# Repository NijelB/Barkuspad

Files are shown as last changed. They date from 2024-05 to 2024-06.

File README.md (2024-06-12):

# Barkuspad
Welcome, here you will find parts and resources for all versions of the Barkus pad. This also includes dance pad firmware for the NanoESP Development board, I hope someday this board, or another ESP32S3-based development board will become the go-to for all DIY game controllers.

# Benifits of ESP32:
### 20 Analog Channels
allowing all kinds of different sensor configs up to 20 sensors.
### USB-C
### 240MHZ Dual core processor
Making it 30x as fast as a 16MHZ USB-C Arduino Micro clone if you use both cores. 1000HZ polling can easily be maintained with this processor even with other heavy loads like a display and Bluetooth. 
### Native HID support
No need for workarounds like UnoJoy that require tampering with the bootloader.
### Native Bluetooth HID support
This could be really cool for travel pads. Imagine embedding this controller within a travel pad and powering it via a UL, CE, Etc... certified USB power bank, we could have cheap and easily made TSA-friendly Bluetooth travel pads.
### Extremely flexible GPIO Pin mapping
### Low cost
A WaveShare dev board can be had for 8$ USD, furthermore, the chip itself costs only 3$ USD.
<br><br>
The ESP32S3 is super promising, I hope to provide a good demonstration of its power to the dance pad community.
<br><br>

# Plastic Parts:
There are folders for most of the 3d printed parts of the pad in here with details such that replacement parts can be made independently. Just open the folder for the version of the pad you have and open the parts folder, then follow the instructions for said part.

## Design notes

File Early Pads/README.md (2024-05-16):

These are all of the early pads that were designed and made, no more than 30 were ever made so they've been put in a seperate folder from the main folder. Due to the low amount of these pads that actually exist and large amount of files there aren't per file printing instructions, but as a baseline:
<br> 40% infill, 2 wall lines, 4 top layers, 4 bottom layers will work for all of the plastic parts here.
<br> 20% gyriod infill, 1 wall line, 4 top, 4 bottom layers will be a good starting point for the TPU parts.

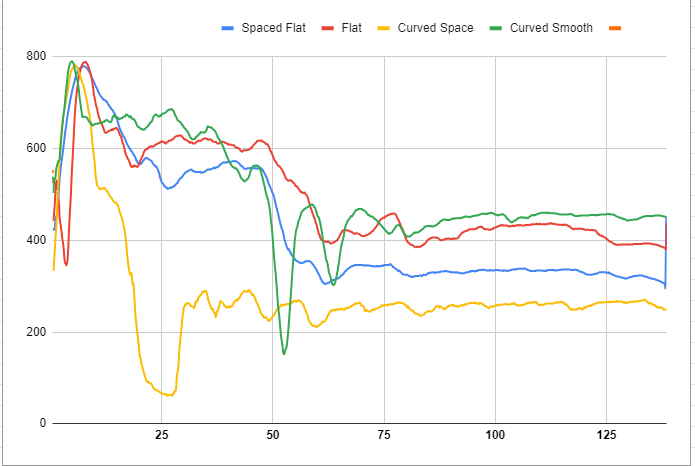
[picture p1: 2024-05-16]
Barkuspad 1_4/sensordata.PNG

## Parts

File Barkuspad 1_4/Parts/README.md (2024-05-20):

Printing instructions:
<p>
Button_base:
<br>-layer height: 0.24mm
<br>-infill: 40%
<br>-wall thickness: 2mm
<br>-top layers: 2
<br>-bottom layers: 4
<p>
Button_Button:
<br>-layer height: 0.24mm
<br>-infill: 40%
<br>-wall thickness: 2mm
<br>-top layers: 2
<br>-bottom layers: 4
<p>
CboxBase:
<br>-layer height: 0.24mm
<br>-infill: 40%
<br>-wall thickness: 1mm
<br>-top layers: 2
<br>-bottom layers: 4
<p>
CboxTop:
<br>-layer height: 0.24mm
<br>-infill: 40%
<br>-wall thickness: 1mm
<br>-top layers: 2
<br>-bottom layers: 6
<p>
Tile_Base:
<br>-layer height: 0.24mm
<br>-infill: 40%
<br>-wall thickness: 1.5mm
<br>-top layers: 2
<br>-bottom layers: 2
<p>
CornerPiece:
<br>-layer height: 0.24mm
<br>-infill: 40%
<br>-wall thickness: 2mm
<br>-top layers: 2
<br>-bottom layers: 4
<p>
GFXClip:
<br>-layer height: 0.24mm
<br>-infill: 40%
<br>-wall thickness: 1mm
<br>-top layers: 4
<br>-bottom layers: 4
<p>
Inner contact base:
<br>-layer height: 0.24mm
<br>-infill: 40%
<br>-wall thickness: 1mm
<br>-top layers: 4
<br>-bottom layers: 4
<p>
Inner contact tpu:
<br>-layer height: 0.24mm
<br>-infill: 60%
<br>-wall thickness: 1mm
<br>-top layers: 2
<br>-bottom layers: 2

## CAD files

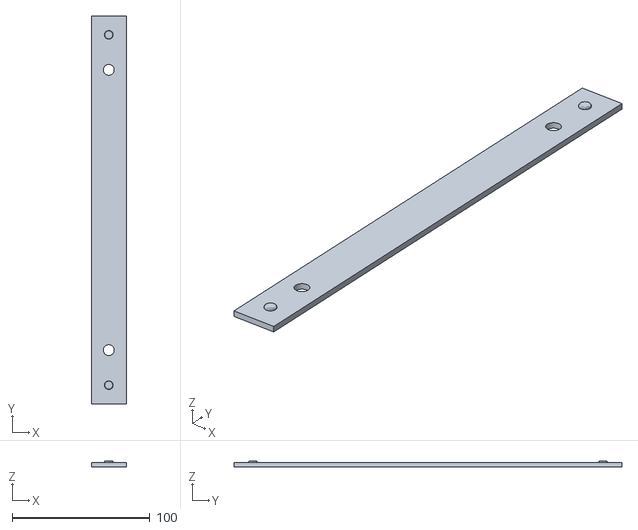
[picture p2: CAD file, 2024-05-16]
Barkuspad 1_4/Parts/Contacts/Outer_contact_spacer.stl
25.1 x 281.3 x 4.44

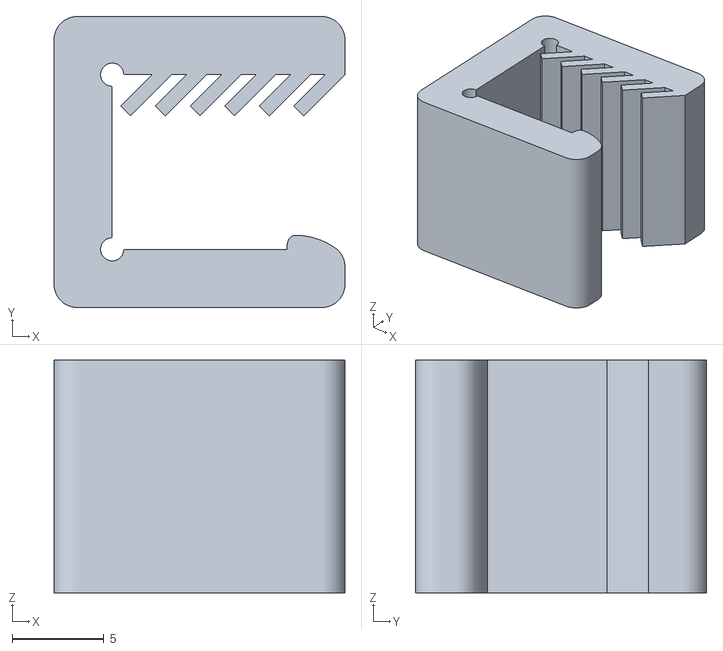
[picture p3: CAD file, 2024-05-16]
Barkuspad 1_4/Parts/GFXClip.stl
15.9 x 15.9 x 12.7

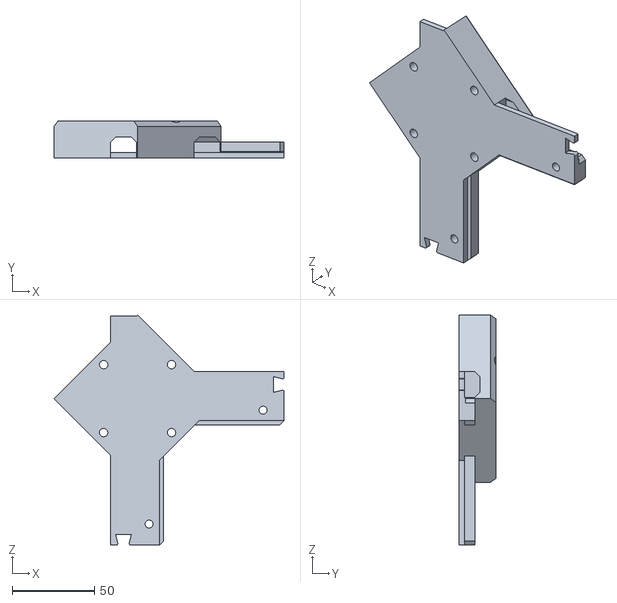
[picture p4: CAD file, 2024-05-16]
Early Pads/Barkuspad 1_1/Parts/BodyPieces/Corner_Brace_1.STL
139.7 x 22.2 x 139.7

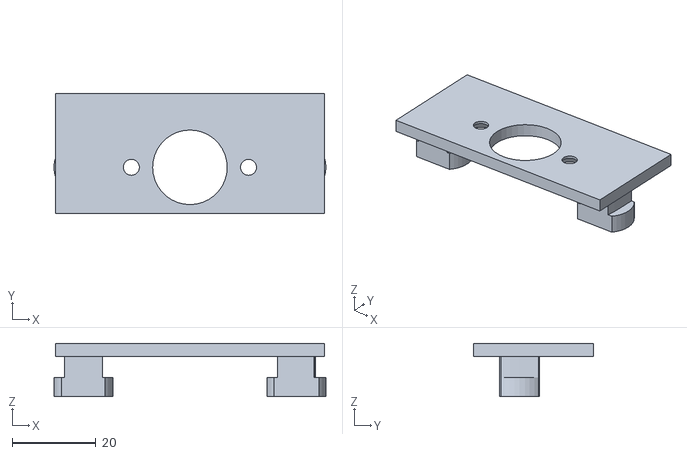
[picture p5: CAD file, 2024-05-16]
Early Pads/Barkuspad 1_1/Parts/Case/MOUNT1_1.STL
64.9 x 28.7 x 12.7

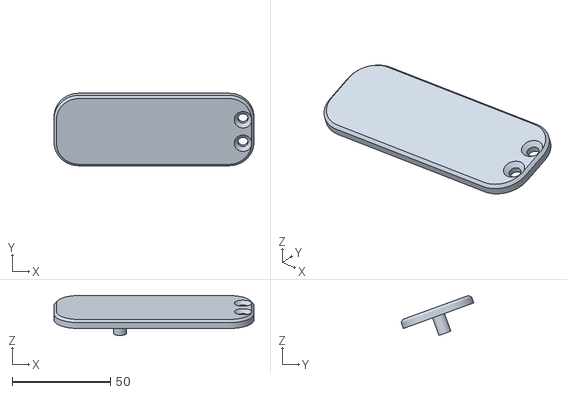
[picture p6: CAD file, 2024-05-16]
Early Pads/Barkuspad 1_1/Parts/Control panel/Start select button.stl
101.6 x 36.9 x 20.3

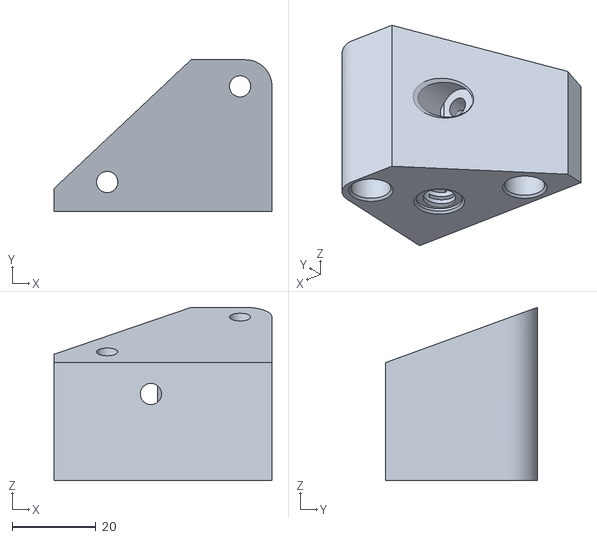
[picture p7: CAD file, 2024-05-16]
Early Pads/Barkuspad 1_1/Parts/PanelPieces/Panel support threaded L.stl
52.1 x 36.2 x 41.4

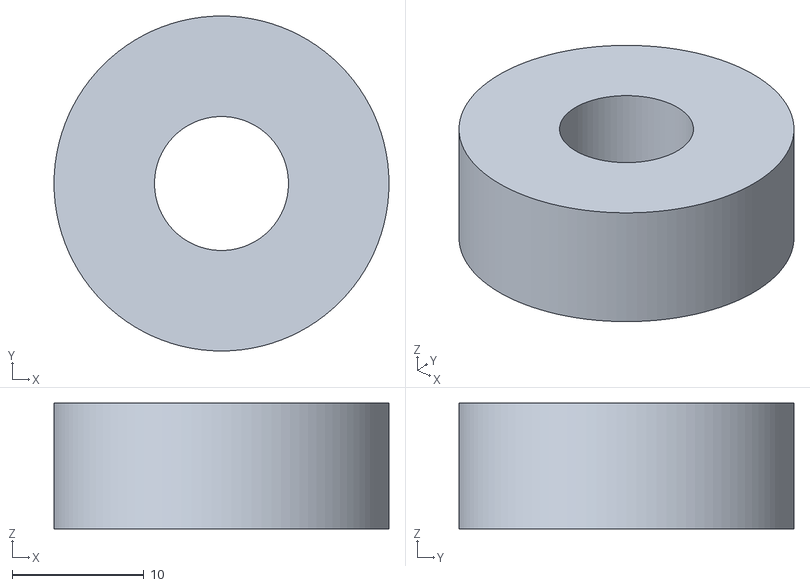
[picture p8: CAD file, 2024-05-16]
Early Pads/Barkuspad 1_1/Parts/Printing Files/New375Support.stl
25.4 x 25.4 x 9.53

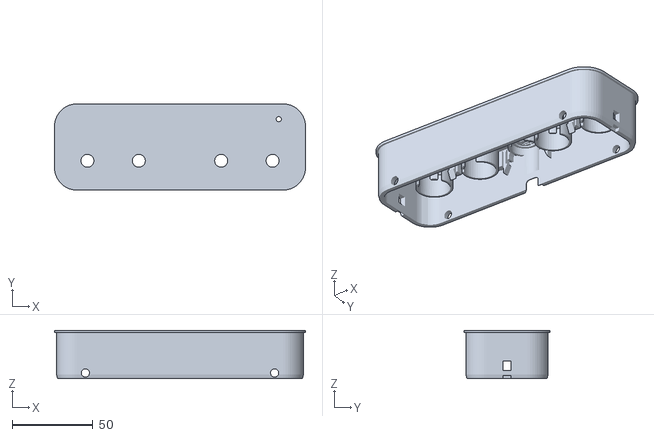
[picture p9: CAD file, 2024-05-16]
Early Pads/Barkuspad 1_2/Parts/Newest_control_box.stl
154.9 x 53.3 x 29.8

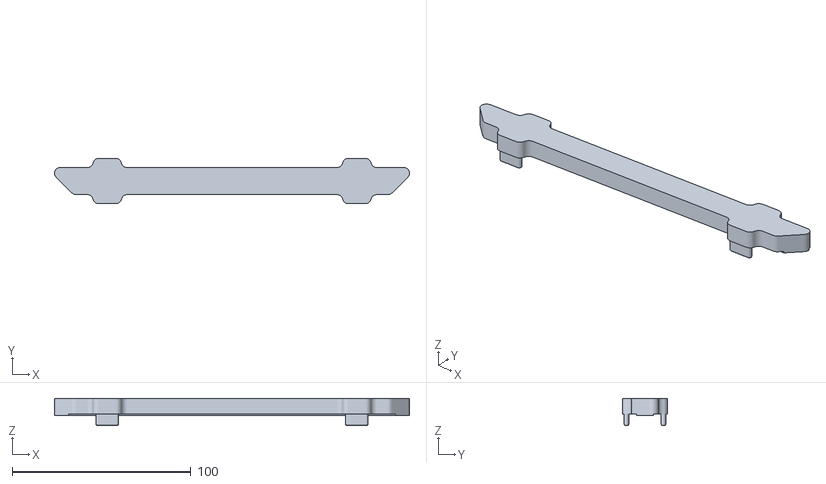
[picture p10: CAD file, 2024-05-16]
Early Pads/Barkuspad 1_3/Parts/Contacts/InnerBumper1.stl
198.8 x 25.4 x 15.3

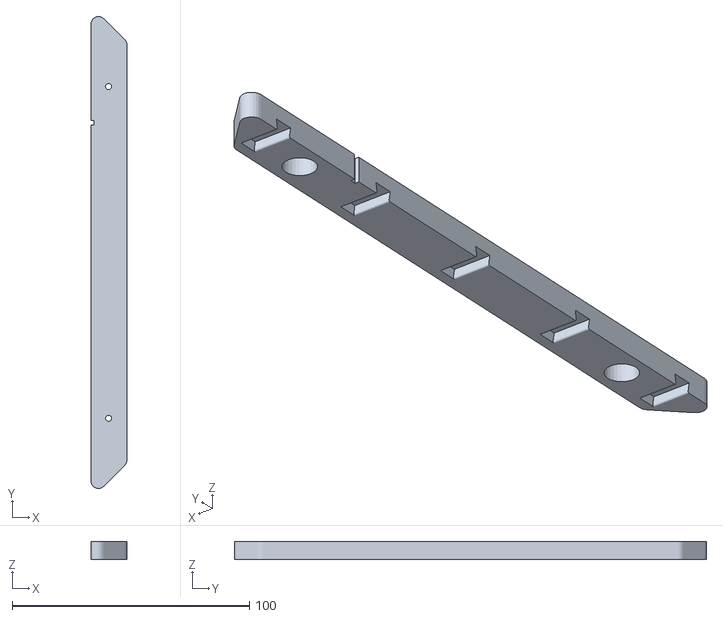
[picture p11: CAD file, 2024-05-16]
Early Pads/Barkuspad 1_3/Parts/Contacts/V2 Bumpers/HardBumberI.stl
15.2 x 198.8 x 7.62

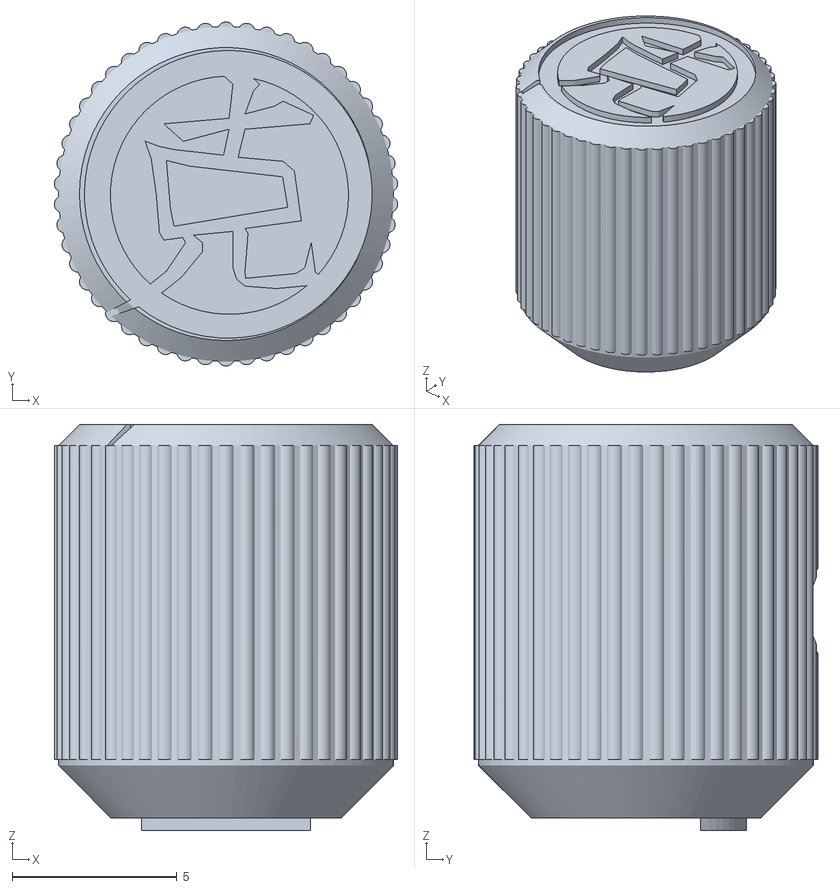
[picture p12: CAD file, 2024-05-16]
Early Pads/Barkuspad 1_3/Parts/knob.stl
10.4 x 10.4 x 12.3

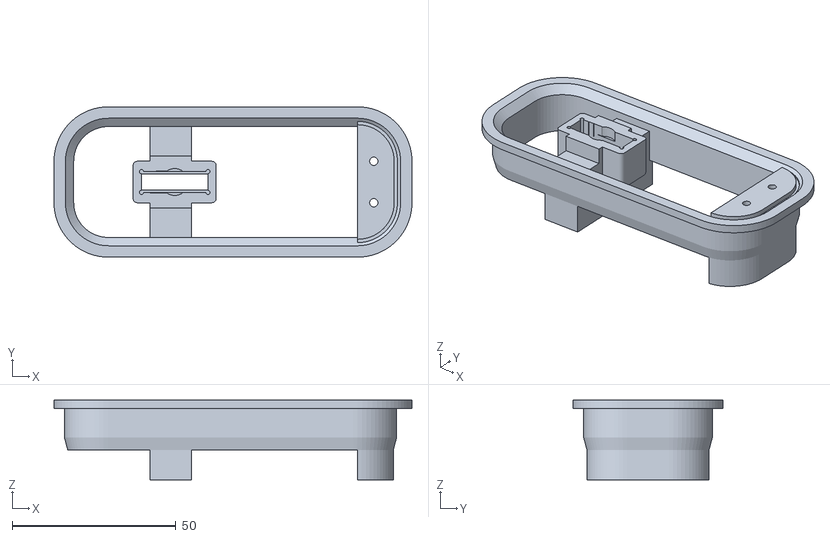
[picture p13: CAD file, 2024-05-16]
Barkuspad 1_4/Parts/Button_base.stl
109.5 x 46.0 x 24.4

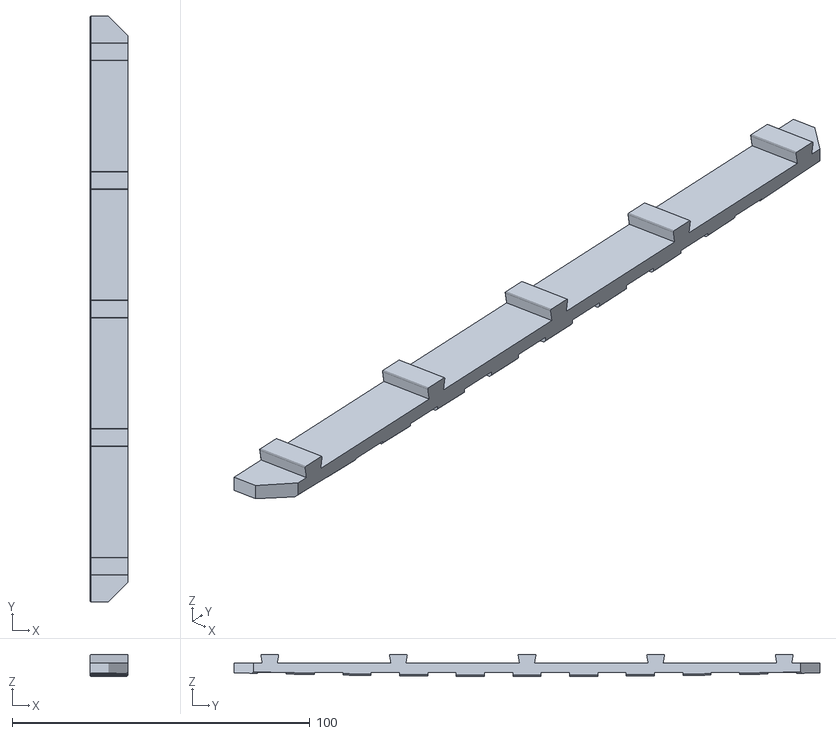
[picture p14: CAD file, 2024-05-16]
Barkuspad 1_4/Parts/Contacts/Inner_contact_tpu_short.stl
12.7 x 196.9 x 7.49

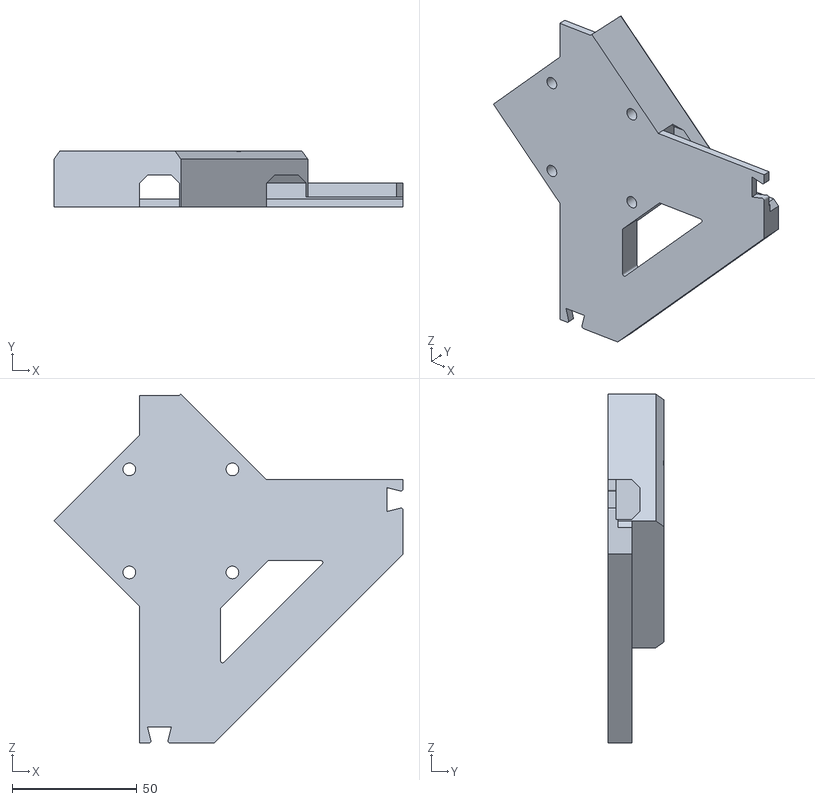
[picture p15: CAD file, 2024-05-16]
Early Pads/Barkuspad 1_1/Parts/BodyPieces/Corner_Brace_3.STL
139.7 x 22.2 x 139.7

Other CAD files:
Early Pads/Barkuspad 1_1/Parts/Case/LID1_1.SLDPRT.STL
Early Pads/Barkuspad 1_1/Parts/Control panel/Start select button base.stl
Early Pads/Barkuspad 1_1/Parts/PanelPieces/Contact.STL
Early Pads/Barkuspad 1_1/Parts/Printing Files/Control Box Cover Ramped.stl
Barkuspad 1_4/Parts/CBoxBot.stl
Barkuspad 1_4/Parts/CBoxTop.stl
Barkuspad 1_4/Parts/Contacts/Inner_contact_base.stl
Barkuspad 1_4/Parts/Contacts/Inner_contact_tpu_tall.stl
Barkuspad 1_4/Parts/CornerPiece.stl
Barkuspad 1_4/Parts/Tile_Base.stl
Barkuspad 1_4/Parts/button_button.stl
Barkuspad 1_4/Parts/knob.stl
Early Pads/Barkuspad 1_1/Parts/BodyPieces/Corner_Brace_2.STL
Early Pads/Barkuspad 1_1/Parts/BodyPieces/Corner_Brace_4.STL
Early Pads/Barkuspad 1_1/Parts/BodyPieces/Corner_Brace_5.STL
Early Pads/Barkuspad 1_1/Parts/BodyPieces/Corner_Brace_6.STL
Early Pads/Barkuspad 1_1/Parts/BodyPieces/Cross_Brace_1.STL
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

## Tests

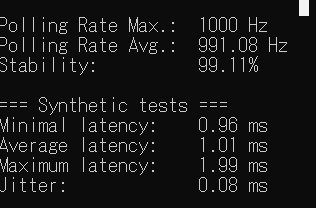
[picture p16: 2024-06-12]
Barkuspad 1_4/Firmware/V8_DUALCORE_MAIN/Testresults.png

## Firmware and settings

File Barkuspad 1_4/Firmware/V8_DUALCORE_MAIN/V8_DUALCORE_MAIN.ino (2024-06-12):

//OBJECTIVES:
//1: Poll at 1000hz 100% stability. 
//2: Have a UI where the user can adjust input sensitivity, see sensor values, and adjust the input pins for backwards compatibility with older pads, or custom pads.
//(3) -- For a later date, setup Bluetooth LE for input. This could be really good for travel pads.


//This sketch uses RTOS, Real Time Operating System. It lets us run the controller on Core1 where it will be uninterupted and is free to run at 1000hz, everything else is on core 0.
//So instead of functions, we have tasks and loops are created from for(;;) instead of loop(). You can still make functions and call them from the tasks but dont add anything to loop(), the reason is loop() runs on core 1 and as previously mentioned, core 1 is reserved for the actual controller input.
//The display can take up to 20ms to render sometimes, during this time previously no other code could run, which is obviously really bad when it comes to having a responsive controller.
//Because loop isnt used we have functions with never ending for(;;) loops. The ESP32 has inbuilt stack overflow protection methods but you still have to be careful what you do with the memory or else it will just crash.
//If you are confused at all the FreeRTOS documentation has really good explanations for everything and there are quite a few basic overviews on youtube.
//TLDR: DO NOT ADD CODE TO THE INPUTCONTROLLER() FUNCTION (or in this case, task), unless it actually has something to do with the controller, that segment needs to be as optimised as possible to maintain good polling rate.

//To program the board you have to press the reset button twice before uploading, it cannot be fast. press 1 second, release one second, press 1 second, release. The light will be a green that fades in and out if you have succeeded.

//THINGS THAT CHANGE BECAUSE WE ARE USING RTOS
//return; is now continue;
//loop() is unused
//we have to manually allocate memory to each task. If you make additions and the board starts crashing you likely need to just increase the #define STACK_SIZE variable to something bigger.

// Serial.println(uxTaskGetStackHighWaterMark(NULL)); <-- USE this command in a function to see how much memory the task uses

#include "USB.h"
#include "USBHIDGamepad.h"
#include <SPI.h>
#include <Wire.h>
#include <Adafruit_GFX.h>
#include <Adafruit_SSD1306.h>
#include <Preferences.h> // ESP32 equivelent of EEPROM

#define SCREEN_WIDTH 128
#define SCREEN_HEIGHT 64
#define OLED_RESET -1
#define SCREEN_ADDRESS 0x3C
#define portTICK_PERIOD_US ( ( TickType_t ) 1000000 / configTICK_RATE_HZ )

#define STACK_SIZE 5000  //They all use ~3200 each so 4000 is a pretty good number

//display stuff
Adafruit_SSD1306 display(SCREEN_WIDTH, SCREEN_HEIGHT, &Wire, OLED_RESET);
int highlightedBar = 3;  // Change this value to highlight a different bar
bool barSelected = false;
int highlightedSetting = 0;
int ButtonHeld = 0;
int refreshInt = 20;

//Settings
String ver = "2024 BARKUS MFG LLC";
enum ScreenSel { //which screen we are on
  MAIN,
  SETTINGS,
  PINREMAP
};
ScreenSel screenSel = MAIN;
bool settingSelected = false;
int scroll = 38;
int pinRemapSel = 0;
int pindex = 0;
bool pinSelected = 0;
int scrollLimit[] = { -52, 38 };
int settings = 9;
int highlightedsetting = 0;
String settingParams[] = { "Back", "Refresh", "Release Thresh", "Press Thresh", "Poll Tester", "Save Settings", "!!Reset All!!", "Inputs", "Pin Remap", "Smoothing" };
int autoSaveInt = 10000;
int autoSaveCounter = 0;
int resetCounter = 0;
int possiblePins[] = {A0, A1, A2, A3, A6, A7, D2, D3};
int smoothingSize = 10; //Window size for sensor smoothing
bool smoothing = true;
unsigned long lastInput;

//Storage
Preferences preferences;

//HID stuff
USBHIDGamepad Gamepad;
bool flipper = false;
bool testPoll = true;

//rotary knob stuff
int CLK_state = 0;
int prev_CLK_state = 0;
int DT_PIN = D7;
int CLK_PIN = D6;
int direction = 0;
int counter;
int buttonPin = D8;
int oldPos = 0;
bool release = true;

////////////////////////////////////////////////////////////////
/**/ int inputPins[] = { A0, A1, A2, A3, A6, A7, D2, D3 };//
////////////////////////////////////////////////////////////////

uint8_t inputs = 4;
int threshVal[] = { 200, 200, 200, 200, 900, 900, 900, 900 };
int sensVal[] = { 40, 70, 30, 50, 10, 70, 10, 10 };
bool bOn[] = { false, false, false, false, false, false, false, false };

//Adjusting these values below may help with jitter inputs (Lightly pressing the tile and getting 10s to 100s of button presses)
int releaseThresh = 10;  //Keep this below press Thresh, default = 10
int pressThresh = 15;    //Keep this above release Thresh, default = 15
void loop() {}           //<== Dont put anything in there
// 'barkusmap', 128x64px
const unsigned char myBitmap[] PROGMEM = {
  0x00, 0x00, 0x00, 0x00, 0x00, 0x00, 0x00, 0x00, 0x00, 0x00, 0x00, 0x00, 0x00, 0x00, 0x00, 0x00,
  0x00, 0x00, 0x00, 0x00, 0x00, 0x00, 0x00, 0x00, 0x60, 0x00, 0x00, 0x00, 0x00, 0x00, 0x00, 0x00,
  0x00, 0x00, 0x00, 0x00, 0x00, 0x00, 0x00, 0x3f, 0xff, 0xe0, 0x00, 0x00, 0x00, 0x00, 0x00, 0x00,
  0x00, 0x00, 0x00, 0x00, 0x00, 0x00, 0x01, 0xff, 0xff, 0xf8, 0x00, 0x00, 0x00, 0x00, 0x00, 0x00,
  0x00, 0x00, 0x00, 0x00, 0x00, 0x00, 0x07, 0xff, 0xff, 0xff, 0x00, 0x00, 0x00, 0x00, 0x00, 0x00,
  0x00, 0x00, 0x00, 0x00, 0x00, 0x00, 0x1f, 0xff, 0xff, 0xff, 0x80, 0x00, 0x00, 0x00, 0x00, 0x00,
  0x00, 0x00, 0x00, 0x00, 0x00, 0x00, 0x7f, 0xff, 0xff, 0xff, 0xe0, 0x00, 0x00, 0x00, 0x00, 0x00,
  0x00, 0x00, 0x00, 0x00, 0x00, 0x00, 0xff, 0xe0, 0x3e, 0x7f, 0xf8, 0x00, 0x00, 0x00, 0x00, 0x00,
  0x00, 0x00, 0x00, 0x00, 0x00, 0x03, 0xff, 0x80, 0x1f, 0x8f, 0xfc, 0x00, 0x00, 0x00, 0x00, 0x00,
  0x00, 0x00, 0x00, 0x00, 0x00, 0x07, 0xfc, 0x00, 0x1f, 0x03, 0xfe, 0x00, 0x00, 0x00, 0x00, 0x00,
  0x00, 0x00, 0x00, 0x00, 0x00, 0x0f, 0xf8, 0x00, 0x1e, 0x00, 0xff, 0x00, 0x00, 0x00, 0x00, 0x00,
  0x00, 0x00, 0x00, 0x00, 0x00, 0x1f, 0xe0, 0x00, 0x1e, 0x00, 0x3f, 0x80, 0x00, 0x00, 0x00, 0x00,
  0x00, 0x00, 0x00, 0x00, 0x00, 0x1f, 0xc0, 0x00, 0x1c, 0x00, 0x1f, 0xc0, 0x00, 0x00, 0x00, 0x00,
  0x00, 0x00, 0x00, 0x00, 0x00, 0x3f, 0x80, 0x00, 0x1c, 0x0f, 0x0f, 0xc0, 0x00, 0x00, 0x00, 0x00,
  0x00, 0x00, 0x00, 0x00, 0x00, 0x7f, 0x00, 0x00, 0x1c, 0xff, 0xe7, 0xe0, 0x00, 0x00, 0x00, 0x00,
  0x00, 0x00, 0x00, 0x00, 0x00, 0xfe, 0x00, 0x00, 0x3f, 0xff, 0xf3, 0xf0, 0x00, 0x00, 0x00, 0x00,
  0x00, 0x00, 0x00, 0x00, 0x00, 0xfc, 0x00, 0x1f, 0xff, 0xff, 0xf1, 0xf8, 0x00, 0x00, 0x00, 0x00,
  0x00, 0x00, 0x00, 0x00, 0x01, 0xf8, 0x07, 0xff, 0xff, 0xc0, 0x01, 0xf8, 0x00, 0x00, 0x00, 0x00,
  0x00, 0x00, 0x00, 0x00, 0x01, 0xf8, 0x03, 0xff, 0x38, 0x00, 0x00, 0xfc, 0x00, 0x00, 0x00, 0x00,
  0x00, 0x00, 0x00, 0x00, 0x03, 0xf0, 0x01, 0xf0, 0x38, 0x00, 0x00, 0x7c, 0x00, 0x00, 0x00, 0x00,
  0x00, 0x00, 0x00, 0x00, 0x03, 0xe0, 0x00, 0x00, 0x38, 0x00, 0x00, 0x7c, 0x00, 0x00, 0x00, 0x00,
  0x00, 0x00, 0x00, 0x00, 0x07, 0xe0, 0x40, 0x00, 0x38, 0x00, 0x00, 0x3e, 0x00, 0x00, 0x00, 0x00,
  0x00, 0x00, 0x00, 0x00, 0x07, 0xe0, 0x78, 0x00, 0x38, 0x00, 0x00, 0x3e, 0x00, 0x00, 0x00, 0x00,
  0x00, 0x00, 0x00, 0x00, 0x07, 0xc0, 0x7f, 0xfc, 0x70, 0x00, 0x00, 0x1f, 0x00, 0x00, 0x00, 0x00,
  0x00, 0x00, 0x00, 0x00, 0x0f, 0xc0, 0x3f, 0xff, 0xfc, 0x00, 0x00, 0x1f, 0x00, 0x00, 0x00, 0x00,
  0x00, 0x00, 0x00, 0x00, 0x0f, 0x80, 0x38, 0x7f, 0xff, 0xfc, 0x00, 0x1f, 0x00, 0x00, 0x00, 0x00,
  0x00, 0x00, 0x00, 0x00, 0x0f, 0x80, 0x38, 0x00, 0xff, 0xfe, 0x00, 0x1f, 0x00, 0x00, 0x00, 0x00,
  0x00, 0x00, 0x00, 0x00, 0x0f, 0x80, 0x38, 0x00, 0x00, 0x7f, 0x00, 0x0f, 0x00, 0x00, 0x00, 0x00,
  0x00, 0x00, 0x00, 0x00, 0x0f, 0x80, 0x38, 0x00, 0x00, 0x03, 0x00, 0x0f, 0x00, 0x00, 0x00, 0x00,
  0x00, 0x00, 0x00, 0x00, 0x0f, 0x80, 0x38, 0x00, 0x00, 0x03, 0x00, 0x0f, 0x80, 0x00, 0x00, 0x00,
  0x00, 0x00, 0x00, 0x00, 0x0f, 0x80, 0x18, 0x00, 0x00, 0x03, 0x80, 0x0f, 0x80, 0x00, 0x00, 0x00,
  0x00, 0x00, 0x00, 0x00, 0x0f, 0x80, 0x18, 0x00, 0x00, 0x03, 0x80, 0x0f, 0x80, 0x00, 0x00, 0x00,
  0x00, 0x00, 0x00, 0x00, 0x1f, 0x80, 0x18, 0x00, 0x00, 0x01, 0x80, 0x0f, 0x80, 0x00, 0x00, 0x00,
  0x00, 0x00, 0x00, 0x00, 0x0f, 0x80, 0x18, 0x00, 0x00, 0x01, 0x80, 0x0f, 0x80, 0x00, 0x00, 0x00,
  0x00, 0x00, 0x00, 0x00, 0x0f, 0x80, 0x18, 0x00, 0x00, 0x01, 0x80, 0x0f, 0x80, 0x00, 0x00, 0x00,
  0x00, 0x00, 0x00, 0x00, 0x0f, 0x80, 0x1c, 0x00, 0x00, 0x0f, 0x80, 0x0f, 0x00, 0x00, 0x00, 0x00,
  0x00, 0x00, 0x00, 0x00, 0x0f, 0x80, 0x1c, 0x00, 0x03, 0xff, 0x80, 0x0f, 0x00, 0x00, 0x00, 0x00,
  0x00, 0x00, 0x00, 0x00, 0x0f, 0x80, 0x1c, 0x00, 0xff, 0xff, 0xc0, 0x0f, 0x00, 0x00, 0x00, 0x00,
  0x00, 0x00, 0x00, 0x00, 0x0f, 0x80, 0x1c, 0x3f, 0xff, 0xe0, 0x00, 0x1f, 0x00, 0x00, 0x00, 0x00,
  0x00, 0x00, 0x00, 0x00, 0x0f, 0xc0, 0x1f, 0xff, 0xfc, 0x00, 0x00, 0x1f, 0x00, 0x00, 0x00, 0x00,
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
};

// 'settingsgear' 8x8px
const unsigned char settmap[] PROGMEM = {
  0x24, 0x00, 0x81, 0x18, 0x18, 0x81, 0x00, 0x24
};

//Sensor value smoothing somewhat similar to the way it works on TeeJUSBs' code. Here we are just calculating WMA instead of WMA and HMA, WMA is already plenty.
class Sensor {
  private:
    int windowSize;
    int* values;
    int currentIndex;

  public:
    Sensor(int windowSize) {
      this->windowSize = windowSize;
      values = new int[windowSize];
      currentIndex = 0;
      for (int i = 0; i < windowSize; i++) {
        values[i] = 0;
      }
    }

    ~Sensor() {
      delete[] values;
    }

    int calculateWMA(int pin_) {
      // Push all values up one index
      for (int i = windowSize - 1; i > 0; i--) {
        values[i] = values[i - 1];
      }
      // Add the new sensor reading at index 0
      values[0] = analogRead(pin_);
      int sum = 0;
      int weight = windowSize;
      for (int i = 0; i < windowSize; i++) {
        sum += values[i] * weight;
        weight--; // Decrease weight for the next value
      }
      return (sum / ((windowSize * (windowSize + 1)) / 2)); // Divide by the sum of the series 1 to windowSize
    }
};

//Would be nice if it could be the same size as the amount of inputs you have selected but the ESP32 is fast enough to cope with the max possible value of 8 and memory fragmentation
//is a very real threat when using RTOS so we will keep it at 8 always
Sensor sensors[8] = {
  Sensor(smoothingSize),
  Sensor(smoothingSize),
  Sensor(smoothingSize),
  Sensor(smoothingSize),
  Sensor(smoothingSize),
  Sensor(smoothingSize),
  Sensor(smoothingSize),
  Sensor(smoothingSize)
};

void setup() {
  //Encoder pin setup
  pinMode(buttonPin, INPUT_PULLUP);
  pinMode(DT_PIN, INPUT_PULLUP);
  pinMode(CLK_PIN, INPUT_PULLUP);

  //Display setup
  if (!display.begin(SSD1306_SWITCHCAPVCC, SCREEN_ADDRESS)) {
    Serial.println(F("SSD1306 allocation failed"));
    for (;;)
      ;  // Don't proceed, loop forever
  }
  display.display();  //Clear Adafruit logo
  delay(2);
  display.clearDisplay();
  display.drawBitmap(0, 0, myBitmap, 128, 64, WHITE);
  display.display();
  delay(5000);  //Change logo displat time here, set to 0 to load immediately <--
  display.clearDisplay();
  
  Gamepad.begin();
  preferences.begin("settings", false); 
  Setting(true, false); // Read settings
  Serial.begin(115200);

  pinMode(inputPins[6], INPUT);
  pinMode(inputPins[7], INPUT);

  xTaskCreatePinnedToCore(
    updateDisplay,
    "DisplayUpdate",
    STACK_SIZE,
    NULL,
    1,
    NULL,
    0);

  xTaskCreatePinnedToCore(
    InputController,
    "controllerinput",
    STACK_SIZE,
    NULL,
    2,
    NULL,
    1);

  xTaskCreatePinnedToCore(
    UIControls,
    "controllerinput",
    STACK_SIZE,
    NULL,
    1,
    NULL,
    0);
}

void Setting(bool ReadOW, bool showMessage){ // First bool decides if you want to read or write to memory, True for read. Second bool decides if you want to display the "settings saved" text
  if (ReadOW == false) { //Write to memory    
    preferences.putBool("testpoll", testPoll);
    preferences.putInt("inputs", inputs);
    for (int i = 0; i < 8; i++) {
      char pointer[50];
      ("thresh" + String(i)).toCharArray(pointer, 50);
      preferences.putInt(pointer, threshVal[i]);
    }
    for (int i = 0; i < 8; i++) {
      char pointer[50];
      ("pinmap" + String(i)).toCharArray(pointer, 50);
      preferences.putInt(pointer, inputPins[i]);
    }
    preferences.putInt("releaseThresh", releaseThresh);
    preferences.putInt("pressThresh", pressThresh);
    preferences.putInt("refreshInt", refreshInt);
  } else { //Read memory
    testPoll = preferences.getBool("testpoll", false);
    inputs = preferences.getInt("inputs", 4);
    for (int i = 0; i < 8; i++) {
      char pointer[50];
      ("thresh" + String(i)).toCharArray(pointer, 50);
      threshVal[i] = preferences.getInt(pointer, 500);
    }
    for (int i = 0; i < 8; i++) {
      char pointer[50];
      ("pinmap" + String(i)).toCharArray(pointer, 50);
      inputPins[i] = preferences.getInt(pointer, possiblePins[i]);
    }
    releaseThresh = preferences.getInt("releaseThresh", 10);
    pressThresh = preferences.getInt("pressThresh", 15);
    refreshInt = preferences.getInt("refreshInt", 20);
  }
  if(showMessage){
    //Show message
  }
}

void SetDefaults(){
  testPoll = false;
    inputs = 4;
    for (int i = 0; i < 8; i++) {
      threshVal[i] = 500;
    }
    for (int i = 0; i < 8; i++) {
      inputPins[i] = possiblePins[i];
    }
    releaseThresh = 10;
    pressThresh = 15;
    refreshInt = 20;
}

void InputController(void* parameters) {
  /* I am faced with an interesting problem here, the ESP32 HID Gamepad library doesnt have a manual send equivelent like Joystick library does. Instead they have .send(ALL OF THE CONTROLLER DATA). So we cant just do setButton(1, on)
  then send the state at the end of the loop. If we do setButton(1, on) for each button the polling rate drops all the way down to 125hz. So Ive gotta figure out how to get this input mask to work for the buttons. */

  for (;;) {
    unsigned long start = micros();
    //MAIN FSR ANALOG READ
    bool buttonInputsMask[32] = {false, false, false, false, false, false, false, false, false, false, false, false, false, false, false, false, false, false, false, false, false, false, false, false, false, false, false, false, false, false, false, false};
    for (int i = 0; i < inputs; i++) {
      if(!smoothing){
        sensVal[i] = analogRead(inputPins[i]);
      }                                                                                                                                                                                                                                  
      else{
        sensVal[i] = sensors[i].calculateWMA(inputPins[i]);
      }
      //Serial.println(sensVal[i]);
      if (sensVal[i] >= threshVal[i] + pressThresh ) {
        buttonInputsMask[i] = true;
        //Gamepad.pressButton(i);
        bOn[i] = true;
        
      } else if (sensVal[i] < threshVal[i] - releaseThresh ) {
        buttonInputsMask[i] = false;
        //Gamepad.releaseButton(i);
        bOn[i] = false;
      }
    }
    //ButtonRead
    for (int i = 0; i < 2; i++) {
      int val = digitalRead(inputPins[6 + i]);
      if (val == HIGH) {
        buttonInputsMask[i + 6] = true;
        bOn[i + 6] = true;
      } else {
        buttonInputsMask[i + 6] = false;
        bOn[i + 6] = false;
      }
    }
    //Convert the 32 digit binary value to a hexidecimal uint32 mask
    uint32_t sendMask = 0;
    for (int i = 0; i < 32; ++i) {
      // Set the corresponding bit in the compressedValue using bitwise OR and left shift
      sendMask |= (buttonInputsMask[i] ? 1 : 0) << i;
    }
    uint32_t hexSendMask = 0x00000000 | sendMask; 
    
    //SEND CONTROLLER STATE
    if (testPoll == false) {
      Gamepad.send(0, 0, 0, 0, 0, 0, 0, 0x00000000 | sendMask);
    }
    else{
      //POLL RATE TESTER
      if (flipper == true) {
        flipper = false;
        Gamepad.send(10, 100, 0, 0, 0, 0, 0, 0x00000006);
      } else {
        flipper = true;
        Gamepad.send(100, 10, 0, 0, 0, 0, 0, 0x00000006);
      }
    }

    //KEEP POLL AT 1000HZ
    unsigned long end = micros();
    unsigned long ellapsed = end - start; 
    unsigned long remainingTime = 1; // remaining time in microseconds
    if(ellapsed < 994){
      remainingTime = 994 - ellapsed;
    }
    vTaskDelay(remainingTime / portTICK_PERIOD_US);
  } 
}

void updateDisplay(void* parameters) {
  for (;;) {
    //Clear display
    display.clearDisplay();
    if (screenSel == MAIN) {
      int barWidth = 128 / inputs - 4;
      //First draw the selection box
      if (highlightedBar != inputs) {
        display.drawRect(highlightedBar * (barWidth + 4), 0, barWidth + 4, 54, WHITE);
      }
      //display.drawRect(x + 6+ thickness, y + thickness, width - 2 * thickness, height - 2 * thickness, BLACK);
      //Draw input data bars
      for (int i = 0; i < inputs; i++) {
        int barHeights = (sensVal[i] / 19);
        int blipPositions = (threshVal[i] / 19);
        display.fillRect(i * (barWidth + 4) + 3, 54 - barHeights, barWidth - 2, barHeights, WHITE);
        int blipColor = WHITE;
        if (barHeights > blipPositions) {
          blipColor = BLACK;
        }
        display.fillRect(i * (barWidth + 4) + 3, 54 - blipPositions, barWidth - 2, 2, blipColor);
      }
      //Draw buttons
      display.setTextSize(0);
      display.fillRect(0, 54, 128, 10, WHITE);
      int selColor = BLACK;
      int startColor = BLACK;
      if (bOn[6]) {
        startColor = WHITE;
      } else {
        startColor = BLACK;
      }
      if (bOn[7]) {
        selColor = WHITE;
      } else {
        selColor = BLACK;
      }
      display.fillRoundRect(1, 55, 50, 8, 2, selColor);
      display.setCursor(14, 56);
      display.setTextColor(!selColor);
      display.println("BACK");
      display.fillRoundRect(128 - 51, 55, 50, 8, 2, startColor);
      display.setCursor(88, 56);
      display.setTextColor(!startColor);
      display.println("START");

      //Draw settings icon
      if (highlightedBar == inputs) {
        display.fillRect(60, 55, 8, 8, BLACK);
        display.drawRect(58, 53, 12, 12, BLACK);
        display.drawBitmap(60, 55, settmap, 8, 8, WHITE);
      } else {
        display.fillRect(60, 55, 8, 8, BLACK);
        display.drawBitmap(60, 55, settmap, 8, 8, WHITE);
      }
    } 
    else if (screenSel == SETTINGS) {  //display settings
      //Setup
      display.setTextColor(WHITE);
      display.drawRect(0, 26, 128, 11, WHITE);
      display.setTextSize(0);
      //Back
      display.setCursor(5, scroll - 10);
      display.println(settingParams[0]);
      //Setting 0
      display.setCursor(5, scroll + 0);
      display.println(settingParams[1]);
      display.setCursor(100, scroll + 0);
      display.println(refreshInt);
      //Setting 1
      display.setCursor(5, scroll + 10);
      display.println(settingParams[2]);
      display.setCursor(100, scroll + 10);
      display.println(releaseThresh);
      //Setting 2
      display.setCursor(5, scroll + 20);
      display.println(settingParams[3]);
      display.setCursor(100, scroll + 20);
      display.println(pressThresh);
      //Setting 3
      display.setCursor(5, scroll + 30);
      display.println(settingParams[4]);
      display.setCursor(100, scroll + 30);
      display.println(testPoll);
      //Setting 4
      display.setCursor(5, scroll + 40);
      display.println(settingParams[5]);
      //Setting 5
      display.setCursor(5, scroll + 50);
      display.println(settingParams[6]);
      //Setting 6
      display.setCursor(5, scroll + 60);
      display.println(settingParams[7]);
      display.setCursor(100, scroll + 60);
      display.println(inputs);
      //Setting 7
      display.setCursor(5, scroll + 70);
      display.println(settingParams[8]);
      //Setting 8
      display.setCursor(5, scroll + 80);
      display.println(settingParams[9]);
      display.setCursor(100, scroll + 80);
      display.println(smoothing);
      //INFO
      display.setCursor(5, scroll + 100);
      display.println(ver);
    }
    else if (screenSel == PINREMAP) {
      //setup
      //draw cursor
      display.setTextColor(WHITE);
      display.drawRect(pinRemapSel * 16, 50, 17, 12, WHITE);
      display.drawRect(pinRemapSel * 16, 18, 17, 12, WHITE);
      display.setTextSize(0);
      //draw labels
      display.setCursor(43, 5);
      display.println("OUTPUT:");
      display.setCursor(5, 20);
      display.println("1");
      display.setCursor(23, 20);
      display.println("2");
      display.setCursor(39, 20);
      display.println("3");
      display.setCursor(53, 20);
      display.println("4");
      display.setCursor(69, 20);
      display.println("5");
      display.setCursor(85, 20);
      display.println("6");
      display.setCursor(99, 20);
      display.println("ST");
      display.setCursor(114, 20);
      display.println("SE");
      display.setCursor(3, 35); 
      display.println("CORRESPONDING PIN:");
      display.setCursor(2, 52);
      display.println(inputPins[0]);
      display.setCursor(21, 52);
      display.println(inputPins[1]);
      display.setCursor(37, 52);
      display.println(inputPins[2]);
      display.setCursor(51, 52);
      display.println(inputPins[3]);
      display.setCursor(67, 52);
      display.println(inputPins[4]);
      display.setCursor(83, 52);
      display.println(inputPins[5]);
      display.setCursor(97, 52);
      display.println(inputPins[6]);
      display.setCursor(112, 52);
      display.println(inputPins[7]);
    }
    //Render result
    display.display();
    vTaskDelay(refreshInt / portTICK_PERIOD_MS);
  }
}
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

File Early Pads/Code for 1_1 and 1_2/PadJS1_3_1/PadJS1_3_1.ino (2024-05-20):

//SCRIPT 1.3.1
//FULL V3 SCRIPT FIRST VERSION
//PAD 1_3_1 FOR USE ONLY ON BOARD VERSION 5
//2024 BARKUS MFG

//SET USB TYPE TO KEYBOARD+MOUSE+JOYSTICK BEFORE UPLOAD
//150MHZ IS ALSO RECCOMENDED AS THE TEENSY 4.0 HAS POOR COOLING

//Axis pins (The arduino / teensy anolog pins connected to each axis) enter in the corresponding order: Left pin, Right pin, Up pin, Down pin
//For example if Left was on 18, Right was on 19, Down 16, and Up 17; aPins would = [18, 19, 16, 17]
//To figure out what pin each tile is bound to, run the test program from the website.

/////////////////////////////////////////////
/**/int aPins[] = {14, 18, 15, 19, 16, 17};// <-- FSR PINS GO HERE: LEFT, LEFT, RIGHT, RIGHT, UP, DOWN (if your pad only has 4 sensor inputs its ok just leave the second left and second right as the default value (18 and 19))
/////////////////////////////////////////////

bool bOn[] = {false, false, false, false, false, false};
bool lOn = false;
bool rOn = false;

//Knob pins (Same concept as above but for the adjustment knobs)
int kPins[] = {20, 20, 21, 21, 22, 23};

//Start and select button pins (Start is the button on the right (Enter) and select is the button on the left (Escape))
int ssPins[] = {9, 10};

//Light stuff
//RGB Values to change color, functional on this version! play around with them as you would like 255 = off 0 = completely on
int RGB[] = {200, 200, 200};
int lPins[] = {2, 3, 4, 5};
int RGBPins[] = {6, 7, 8};

//Adjusting these values below may help with jitter inputs (Lightly pressing the tile and getting 10s to 100s of button presses)
int releaseThresh = 10; //Keep this below press Thresh, default = 10
int pressThresh = 15; //Keep this above release Thresh, default = 15

void setup() {
  // setup button pins
  pinMode(ssPins[0], INPUT);
  pinMode(ssPins[1], INPUT);

  // put your setup code here, to run once:
  Joystick.begin();
  Serial.begin(9600);

  //Set RGB Values
  for (int i = 0; i < 3; i++) {
    analogWrite(RGBPins[i], RGB[i]);
  }

  //Stop random button input
  for (int i = 0; i < 32; i++) {
    Joystick.button(i, 0);
  }

  Joystick.useManualSend(true);
}

void loop() {
  // put your main code here, to run repeatedly:

  // Iterate through all FSR input values to determine if they are greater than the knob values
  for (int i = 0; i < 6; i++) 
  {
    if(analogRead(aPins[i]) >= analogRead(kPins[i]) + pressThresh && bOn[i] == false) {
      Joystick.button(i + 1, 1);
      bOn[i] = true;
      digitalWrite(lPins[i], HIGH);

      // Check if one of the two left or right sensors is on
      if(i == 0 || 1){
        lOn = true;
      }

      if(i == 2 || 3){
        rOn = true;
      }
    }
    else if (analogRead(aPins[i]) < analogRead(kPins[i]) - releaseThresh && bOn[i] == true) {
      Joystick.button(i + 1, 0);
      bOn[i] = false;
      digitalWrite(lPins[i], LOW);
    }
  }
  // Check if both of the two left or right sensors is off
  if(bOn[0] && bOn[1] == false){
    lOn = false;
  }
  if(bOn[2] && bOn[3] == false){
    rOn = false;
  }

  // If any of the left FSRS are actuated, call left
  if(lOn == true) {
    digitalWrite(lPins[0], HIGH);
    Joystick.button(0 + 1, 1);
    Joystick.button(1 + 1, 1);
  }
  //if both of the left FSRS are unactuated, turn off left
  else{
    digitalWrite(lPins[0], LOW);
    Joystick.button(0 + 1, 0);
    Joystick.button(1 + 1, 0);
  }
  // If any of the right FSRS are actuated, call right 
  if(rOn == true) {
    digitalWrite(lPins[1], HIGH);
    Joystick.button(2 + 1, 1);
    Joystick.button(3 + 1, 1);
  }
  //if both of the right FSRS are unactuated, turn off right
  else{
    digitalWrite(lPins[1], LOW);
    Joystick.button(2 + 1, 0);
    Joystick.button(3 + 1, 0);
  }

  // Iterate through button inputs (start and select)
  for (int i = 0; i < 2; i++) 
  {
    if(digitalRead(ssPins[i]) == HIGH) {
      Joystick.button(i + 5, 1);
    }
    else {
      Joystick.button(i + 5, 0);
    }
  }
  Joystick.send_now();
}

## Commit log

2024-05-16 Uploaded all the STL Files for all the pads I have made
    They get progressively more organized going from 1_1 -> 1_4
    [BASE1_1.STL, BASE1_2.STL, BASE2.STL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]
2024-06-12 Added new polling rate results
    The old poll results would read 1100 - 900 randomly, now it is locked down to 990 - 1000 for a pretty consistent 1000hz poll
